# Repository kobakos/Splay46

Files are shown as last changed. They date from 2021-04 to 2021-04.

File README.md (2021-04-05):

# Splay46
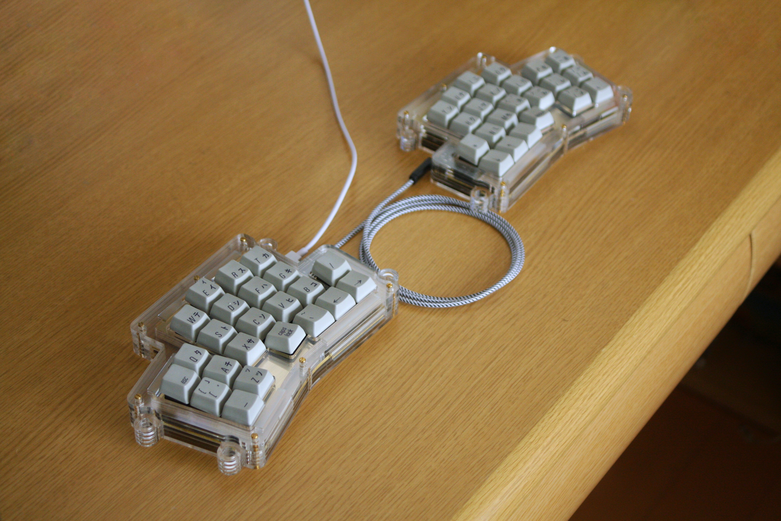
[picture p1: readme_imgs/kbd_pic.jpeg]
KBD_IMAGE

## Build guide
***This keyboard requires soldering of really small smd components like USB Type C Receptacle(0.3mm pitch), Atmega32U4(0.8mm pitch), 0603(1608 in metric) sized capacitors/resistors, thus only recommended for experts.***

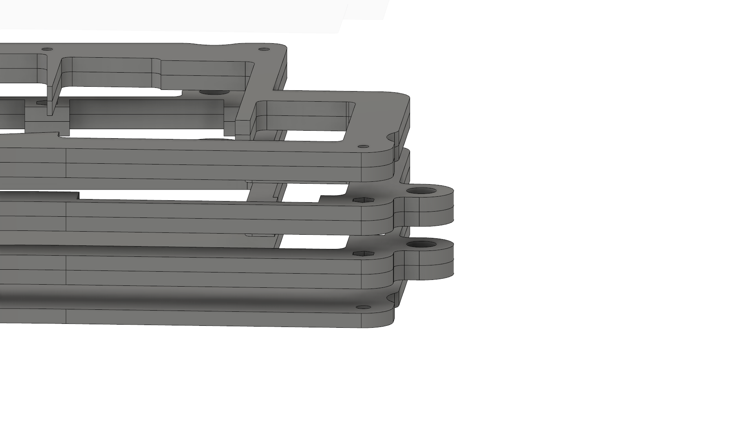
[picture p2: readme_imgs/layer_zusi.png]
Layers

 I will refer to these four sections of the case as bottom, mid-low , mid-hi, top, from bottom to top.
## Getting all the parts you'll need
- PCB(gerbers are in this repository. Hot-swappable version(only MX series) and ALPS compatible version(non hot-swappable) is available.)
- Components(check the BOM).
- Case(dxf is in this repository)
- Plate(dxf is in this repository. MX or ALPS)
- Gaskets *20
- M2 screws *28
- M2 spacers (length depends on the mid layer thickness) *14
- M6 nuts *8 (for tenting/tilting)
- M6 bolts *16 (for tenting/tilting)
- rubber feets *some
- keyswitches * 46
### BOM

| Annotation(Silk) | Component | digikey product number | 
| --- | --- | --- |
| C1 | 10uf capacitor | 1276-1119-1-ND | 
| C2,5,6 | 0.1uf capacitor | 1276-CL10B104KB8NNNLCT-ND | 
| C3,4 | 22pf capacitor | 478-1167-1-ND | 
| C7 | 1uf capacitor | 276-1102-1-ND | 
| R1,2 | 22ohm resistor | 311-22.0HRCT-ND | 
| R3,4 | 10kohm resistor | 311-10KDCT-ND | 
| R5,6 | 5.1kohm resistor | 311-5.10KHRCT-ND | 
| Y1 | 16.0Mhz crystal | SER4069CT-ND | 
| U1 | Atmega32U4 | ATMEGA32U4-AURCT-ND | 
| SW1 | Tactile switch | CKN10361CT-ND | 
| D1-23 | smd Diode | SMMSD4148T1GOSCT-ND | 
| J1 | USB type-c receptacle | 2073-USB4105-GF-ACT-ND | 
| J2 | TRS jack | CP-3502SJCT-ND | 
| MX1-23 | Kailh MX switch socket(optional) | - | 
### Getting the case
This case was made to be stacked with 2, 3, 3, 3, 2.5, 3, 3 mm thick acryilc plate(from bottom to top). But if you are thinking of ordering the acrylics to elecrow, it will be costly to do so with these layer thicknesses, so instead you can set all layer's thickness as 3mm. You can use the whole_3030.dxf in that case.
### Spacer size/ length
The hex hole on the mid layer is a hexagon that circumscribes with a circle with 4.2mm radius, and the hole on the top/bottom layer is a circle with 2.2mm radius.
Spacer length should be the same as the thickness of the mid-hi layer + mid-low layer.
### Gasket thickness
Thickness of the gaskets depends on the mid-hi layer's thickness. If you are using 2.5mm plate and 3.0mm plate for the mid-hi layer with a 1.5mm thick plate, the gasket thickness would be 2mm. Generally, (gasket thickness) = ((mid-hi layer thickness) - (plate thickness)) /2
## Soldering the components onto the pcb(except the switches)
Place the components below to its corresponding silks and solder them. The placement of the MCU and the diode have to be done carefully accroding to the picture below. The rest of it doesn't care about placement angle as long as it matches the footprint. Check out some SMD soldering tutorials on youtube if you are worried about soldering these components.
Check if there are no soldering defects, and plug it in to the pc to see if the pcb is working properly.
## Placing the switches
Insert the switches to the plate, then solder(or just insert, if you are working on a hot-swappable pcb) them to the pcb.
## Flashing the firmware
Download the firmware in this repository and move it under QMK's keyboards folder. Check https://beta.docs.qmk.fm/using-qmk/guides/flashing/flashing how to flash. This keybaord use DFU as bootloader and EEPROM to define the handedness so for example if you are flashing the default firmware with the left hand side connected to the pc, you can do that by running ```make splay46:default:dfu-split-left```.
## Assembling the case
Stick the gaskets to the plate. Stack the first three layer (bottom and mid-low), place the plate and pcb on top of it. Place rest of the acrylics, adjust the placement, then screw them.

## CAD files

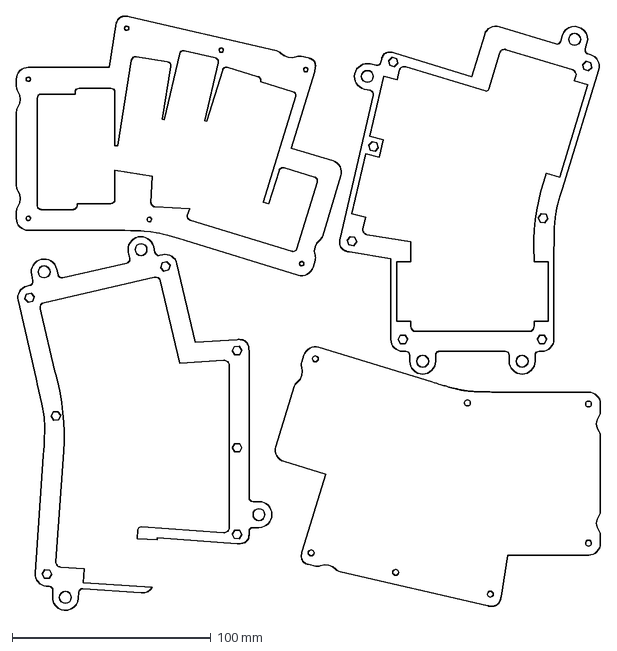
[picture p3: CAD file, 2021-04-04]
case_dxf/whole_3030.dxf
293.7 x 299.2 mm

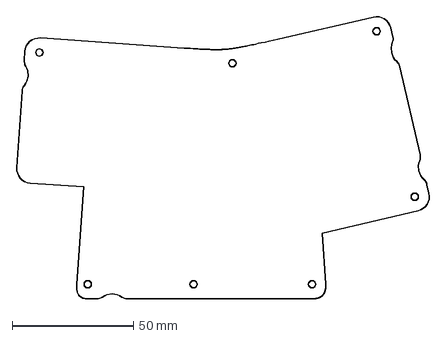
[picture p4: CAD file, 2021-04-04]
case_dxf/bottom.dxf
170.9 x 116.5 mm

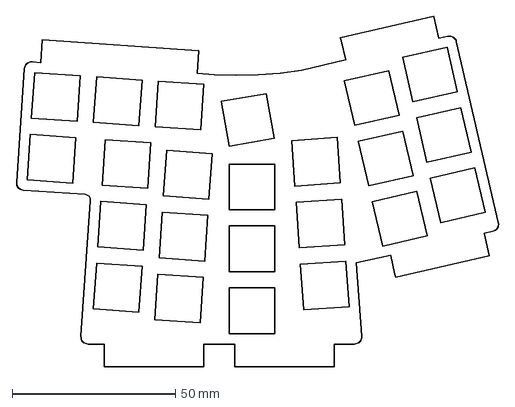
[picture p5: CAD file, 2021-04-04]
plate_dxf/plate_mx.dxf
147.9 x 107.5 mm

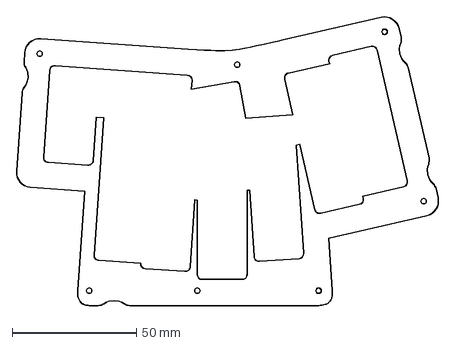
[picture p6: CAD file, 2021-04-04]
case_dxf/top.dxf
170.5 x 116.5 mm

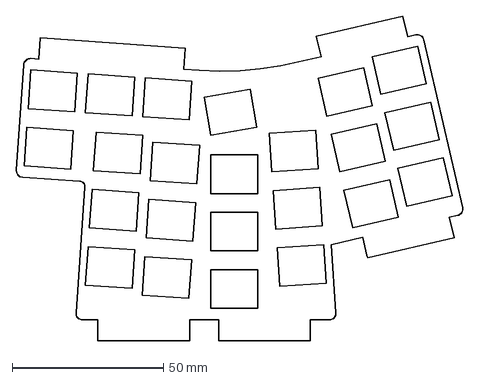
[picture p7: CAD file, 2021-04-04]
plate_dxf/plate_alps.dxf
147.9 x 107.5 mm

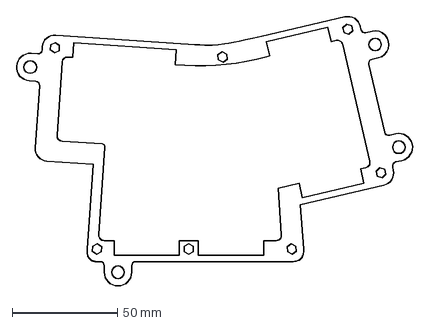
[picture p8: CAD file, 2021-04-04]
case_dxf/mid_hi.dxf
188.8 x 128.0 mm

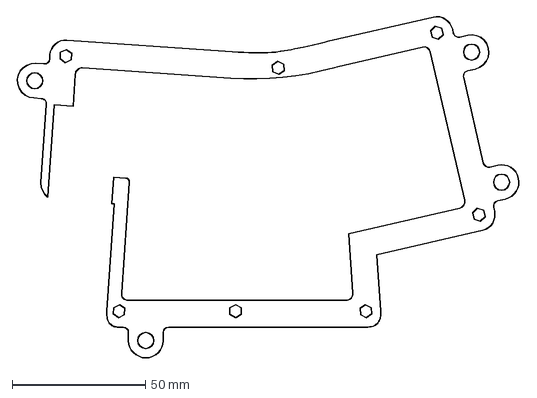
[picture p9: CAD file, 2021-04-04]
case_dxf/mid_low.dxf
188.9 x 128.0 mm

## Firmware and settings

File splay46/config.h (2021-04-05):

/*
Copyright 2021 kobakos

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
You should have received a copy of the GNU General Public License
along with this program.  If not, see <http://www.gnu.org/licenses/>.
*/

#pragma once

#include "config_common.h"

/* USB Device descriptor parameter */
#define VENDOR_ID 0xFEED
#define PRODUCT_ID 0x0000
#define DEVICE_VER 0x0001
#define MANUFACTURER kobakos
#define PRODUCT Splay46
#define DESCRIPTION stacked acrylic keyboard designed by kobakos

/* key matrix size */
#define MATRIX_ROWS 8
#define MATRIX_COLS 6

#define EE_HANDS

/*
 * Keyboard Matrix Assignments
 *
 * Change this to how you wired your keyboard
 * COLS: AVR pins used for columns, left to right
 * ROWS: AVR pins used for rows, top to bottom
 * DIODE_DIRECTION: COL2ROW = COL = Anode (+), ROW = Cathode (-, marked on diode)
 *                  ROW2COL = ROW = Anode (+), COL = Cathode (-, marked on diode)
 *
 */
 
#define MATRIX_ROW_PINS {F0, F1, F4, D6}
#define MATRIX_COL_PINS {F5, F6, F7, D7, D5, B0}
#define MATRIX_ROW_PINS_RIGHT {D4, D6, D7, F1}
#define MATRIX_COL_PINS_RIGHT {D5, F0, F4, B6, B5, B4}
#define UNUSED_PINS

/* COL2ROW, ROW2COL*/ 
#define DIODE_DIRECTION COL2ROW

/*
 * Split Keyboard specific options, make sure you have 'SPLIT_KEYBOARD = yes' in your rules.mk, and define SOFT_SERIAL_PIN. 
 */
#define SPLIT_USB_DETECT
#define SPLIT_USB_TIMEOUT 2000
#define USE_SERIAL
#define SOFT_SERIAL_PIN D0  // or D1, D2, D3, E6

// #define BACKLIGHT_PIN B7
// #define BACKLIGHT_BREATHING
// #define BACKLIGHT_LEVELS 3

// #define RGB_DI_PIN E2
// #ifdef RGB_DI_PIN
//   #define RGBLED_NUM 16
//   #define RGBLIGHT_HUE_STEP 8
//   #define RGBLIGHT_SAT_STEP 8
//   #define RGBLIGHT_VAL_STEP 8
//   #define RGBLIGHT_LIMIT_VAL 255 /* The maximum brightness level */
//   #define RGBLIGHT_SLEEP  /* If defined, the RGB lighting will be switched off when the host goes to sleep */
// /*== all animations enable ==*/
//   #define RGBLIGHT_ANIMATIONS
// /*== or choose animations ==*/
//   #define RGBLIGHT_EFFECT_BREATHING
//   #define RGBLIGHT_EFFECT_RAINBOW_MOOD
//   #define RGBLIGHT_EFFECT_RAINBOW_SWIRL
//   #define RGBLIGHT_EFFECT_SNAKE
//   #define RGBLIGHT_EFFECT_KNIGHT
//   #define RGBLIGHT_EFFECT_CHRISTMAS
//   #define RGBLIGHT_EFFECT_STATIC_GRADIENT
//   #define RGBLIGHT_EFFECT_RGB_TEST
//   #define RGBLIGHT_EFFECT_ALTERNATING
// /*== customize breathing effect ==*/
//   /*==== (DEFAULT) use fixed table instead of exp() and sin() ====*/
//   #define RGBLIGHT_BREATHE_TABLE_SIZE 256      // 256(default) or 128 or 64
//   /*==== use exp() and sin() ====*/
//   #define RGBLIGHT_EFFECT_BREATHE_CENTER 1.85  // 1 to 2.7
//   #define RGBLIGHT_EFFECT_BREATHE_MAX    255   // 0 to 255
// #endif

/* Debounce reduces chatter (unintended double-presses) - set 0 if debouncing is not needed */
#define DEBOUNCE 5

/* define if matrix has ghost (lacks anti-ghosting diodes) */
//#define MATRIX_HAS_GHOST

/* Mechanical locking support. Use KC_LCAP, KC_LNUM or KC_LSCR instead in keymap */
#define LOCKING_SUPPORT_ENABLE
/* Locking resynchronize hack */
#define LOCKING_RESYNC_ENABLE

/* If defined, GRAVE_ESC will always act as ESC when CTRL is held.
 * This is userful for the Windows task manager shortcut (ctrl+shift+esc).
 */
// #define GRAVE_ESC_CTRL_OVERRIDE

/*
 * Force NKRO
 *
 * Force NKRO (nKey Rollover) to be enabled by default, regardless of the saved
 * state in the bootmagic EEPROM settings. (Note that NKRO must be enabled in the
 * makefile for this to work.)
 *
 * If forced on, NKRO can be disabled via magic key (default = LShift+RShift+N)
 * until the next keyboard reset.
 *
 * NKRO may prevent your keystrokes from being detected in the BIOS, but it is
 * fully operational during normal computer usage.
 *
 * For a less heavy-handed approach, enable NKRO via magic key (LShift+RShift+N)
 * or via bootmagic (hold SPACE+N while plugging in the keyboard). Once set by
 * bootmagic, NKRO mode will always be enabled until it is toggled again during a
 * power-up.
 *
 */
//#define FORCE_NKRO

/*
 * Magic Key Options
 *
 * Magic keys are hotkey commands that allow control over firmware functions of
 * the keyboard. They are best used in combination with the HID Listen program,
 * found here: https://www.pjrc.com/teensy/hid_listen.html
 *
 * The options below allow the magic key functionality to be changed. This is
 * useful if your keyboard/keypad is missing keys and you want magic key support.
 *
 */

/* key combination for magic key command */
/* defined by default; to change, uncomment and set to the combination you want */
// #define IS_COMMAND() (get_mods() == MOD_MASK_SHIFT)

/* control how magic key switches layers */
//#define MAGIC_KEY_SWITCH_LAYER_WITH_FKEYS  true
//#define MAGIC_KEY_SWITCH_LAYER_WITH_NKEYS  true
//#define MAGIC_KEY_SWITCH_LAYER_WITH_CUSTOM false
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

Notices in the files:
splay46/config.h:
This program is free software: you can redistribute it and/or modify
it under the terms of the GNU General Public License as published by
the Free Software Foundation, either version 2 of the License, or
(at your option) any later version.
